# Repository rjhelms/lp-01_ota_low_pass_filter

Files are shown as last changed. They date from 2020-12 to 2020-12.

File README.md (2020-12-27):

# LP-01 OTA Low Pass Filter
[][cc-by-sa]

A Eurorack low-pass filter, in the style of the classic MS-20 circuit, featuring two CV inputs - one adjustable, the other with roughly 1V/oct tracking.

* Width: 8hp
* Depth: 23mm

This project was created with [KiCad](https://kicad.org/).

This work licensed under a
[Creative Commons Attribution-ShareAlike 4.0 International License][cc-by-sa].

[][cc-by-sa]

[cc-by-sa]: http://creativecommons.org/licenses/by-sa/4.0/
[cc-by-sa-image]: https://licensebuttons.net/l/by-sa/4.0/88x31.png
[cc-by-sa-shield]: https://img.shields.io/badge/License-CC%20BY--SA%204.0-lightgrey.svg

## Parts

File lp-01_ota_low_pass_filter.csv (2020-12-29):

Reference | Quantity | Value | Footprint | Datasheet | MFN | Manufacturer | Vendor
C11 C10 C7 C6 C3 C4 | 6 | 100n | Capacitor_THT:C_Disc_D5.0mm_W2.5mm_P2.50mm | ~ | K104K15X7RF5TL2 | Vishay | Digi-Key
C12 | 1 | 470n | Capacitor_THT:C_Disc_D5.0mm_W2.5mm_P2.50mm | ~ | FG18X7R1H474KRT00 | TDK | Digi-Key
C2 C1 | 2 | 10u | Capacitor_THT:CP_Radial_D4.0mm_P1.50mm | ~ | USR1E100MDD1TP | Nichicon | Digi-Key
C5 | 1 | 4n7 | Capacitor_THT:C_Disc_D5.0mm_W2.5mm_P2.50mm | ~ | K472K15X7RH5TL2 | Vishay | Digi-Key
C8 C9 | 2 | 1n | Capacitor_THT:C_Disc_D5.0mm_W2.5mm_P2.50mm | ~ | SR201A102JAR | AVX | Digi-Key
D1 D2 | 2 | LED Green | LED_THT:LED_D5.0mm | ~ | SLR-56MC3F | Rohm | Digi-Key
J3 J1 J2 J4 | 4 | AudioJack2 | Connector_Audio:Jack_3.5mm_QingPu_WQP-PJ398SM_Vertical_CircularHoles | ~ | WQP-PJ398SM | QingPu | Thonk
J5 | 1 | Conn_02x05_Odd_Even | Connector_PinHeader_2.54mm:PinHeader_2x05_P2.54mm_Vertical | ~ | 67997-410HLF | Amphenol ICC / FCI | Digi-Key
Q1 Q2 | 2 | 2N3906 | Package_TO_SOT_THT:TO-92_Inline_Wide | https://www.fairchildsemi.com/datasheets/2N/2N3906.pdf | 2N3906-AP | MCC | Digi-Key
R1 | 1 | 47K | Resistor_THT:R_Axial_DIN0204_L3.6mm_D1.6mm_P5.08mm_Horizontal | ~ | RNMF14FTC47K0 | Stackpole | Digi-Key
R14 R6 R16 R10 R15 R13 | 6 | 10K | Resistor_THT:R_Axial_DIN0204_L3.6mm_D1.6mm_P5.08mm_Horizontal | ~ | RNMF14FAD10K0 | Stackpole | Digi-Key
R17 | 1 | 68K | Resistor_THT:R_Axial_DIN0204_L3.6mm_D1.6mm_P5.08mm_Horizontal | ~ | RNMF14FTC68K0 | Stackpole | Digi-Key
R19 | 1 | 1K0 | Resistor_THT:R_Axial_DIN0204_L3.6mm_D1.6mm_P5.08mm_Horizontal | ~ | RNF18FTD1K00 | Stackpole | Digi-Key
R2 R18 | 2 | 220K | Resistor_THT:R_Axial_DIN0204_L3.6mm_D1.6mm_P5.08mm_Horizontal | ~ | RNMF14FTC220K | Stackpole | Digi-Key
R3 | 1 | 100K | Resistor_THT:R_Axial_DIN0204_L3.6mm_D1.6mm_P5.08mm_Horizontal | ~ | RNF18FTD100K | Stackpole | Digi-Key
R4 | 1 | 4K7 | Resistor_THT:R_Axial_DIN0204_L3.6mm_D1.6mm_P5.08mm_Horizontal | ~ | RNMF14FTC4K70 | Stackpole | Digi-Key
R5 | 1 | 470K | Resistor_THT:R_Axial_DIN0204_L3.6mm_D1.6mm_P5.08mm_Horizontal | ~ | CF18JT470K | Stackpole | Digi-Key
R8 R7 R12 R11 | 4 | 220R | Resistor_THT:R_Axial_DIN0204_L3.6mm_D1.6mm_P5.08mm_Horizontal | ~ | RNMF14FTC220R | Stackpole | Digi-Key
R9 | 1 | 1K8 | Resistor_THT:R_Axial_DIN0204_L3.6mm_D1.6mm_P5.08mm_Horizontal | ~ | RNMF14FTC1K80 | Stackpole | Digi-Key
RV1 RV4 | 2 | B100K | Potentiometer_THT:Potentiometer_Alpha_RD901F-40-00D_Single_Vertical | ~ | RD901F-40-15F-B100K | Alpha | Thonk
RV3 RV2 | 2 | 10K | Potentiometer_Custom:Potentiometer_Bourns_PV36W | ~ | PV36X103C01B00 | Bourns | Digi-Key
RV5 | 1 | A100K | Potentiometer_THT:Potentiometer_Alpha_RD901F-40-00D_Single_Vertical | ~ | RD901F-40-15F-A100K | Alpha | Thonk
U1 | 1 | TL072 | Package_DIP:DIP-8_W7.62mm_Socket | http://www.ti.com/lit/ds/symlink/tl071.pdf | TL072IP | Texas Instruments | Digi-Key
U2 | 1 | LM13700 | Package_DIP:DIP-16_W7.62mm_Socket | http://www.ti.com/lit/ds/symlink/lm13700.pdf | LM13700N/NOPB | Texas Instruments | Digi-Key
U3 | 1 | TL074 | Package_DIP:DIP-14_W7.62mm_Socket | http://www.ti.com/lit/ds/symlink/tl071.pdf | TL074CN | Texas Instruments | Digi-Key
U1 | 1 | DIP-8 socket | Package_DIP:DIP-8_W7.62mm_Socket |  | ED08DT | On Shore Technology | Digi-Key
U2 | 1 | DIP-16 socket | Package_DIP:DIP-16_W7.62mm_Socket |  | ED16DT | On Shore Technology | Digi-Key
U3 | 1 | DIP-14 socket | Package_DIP:DIP-14_W7.62mm_Socket |  | ED14DT | On Shore Technology | Digi-Key

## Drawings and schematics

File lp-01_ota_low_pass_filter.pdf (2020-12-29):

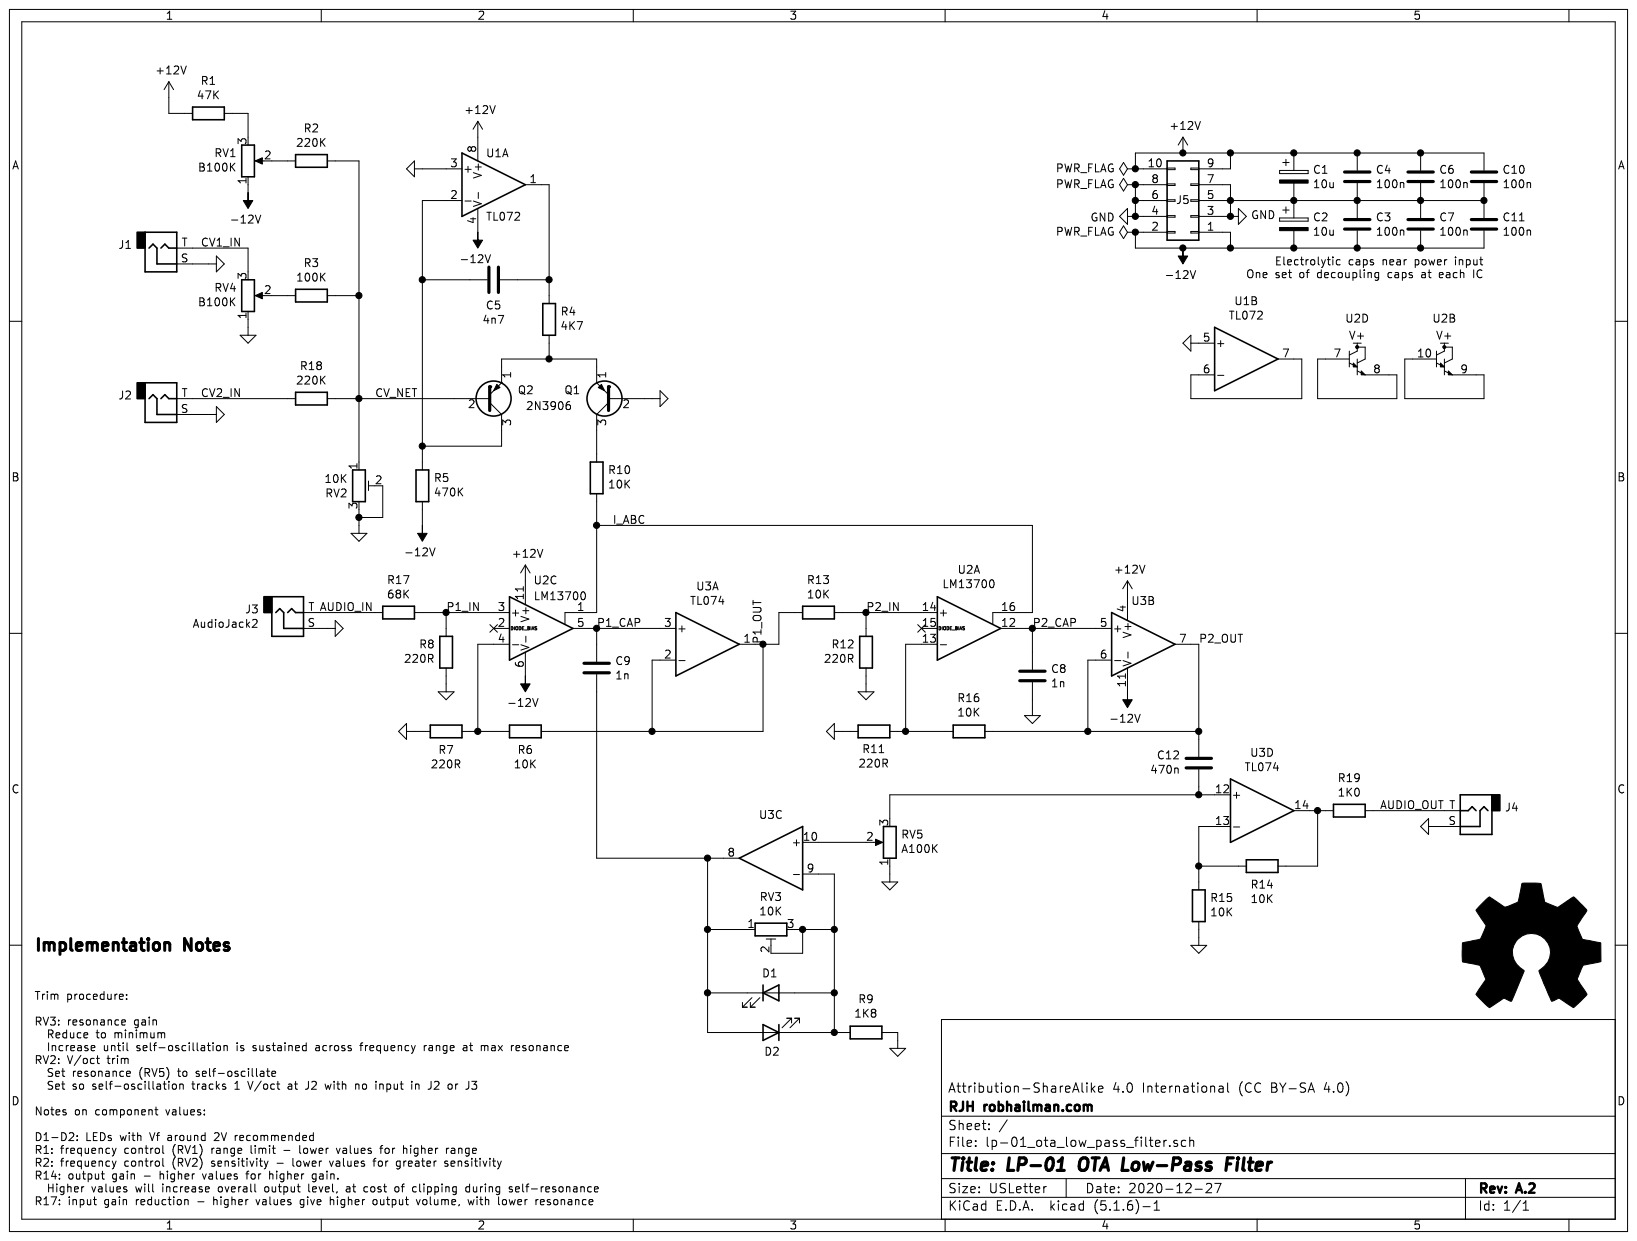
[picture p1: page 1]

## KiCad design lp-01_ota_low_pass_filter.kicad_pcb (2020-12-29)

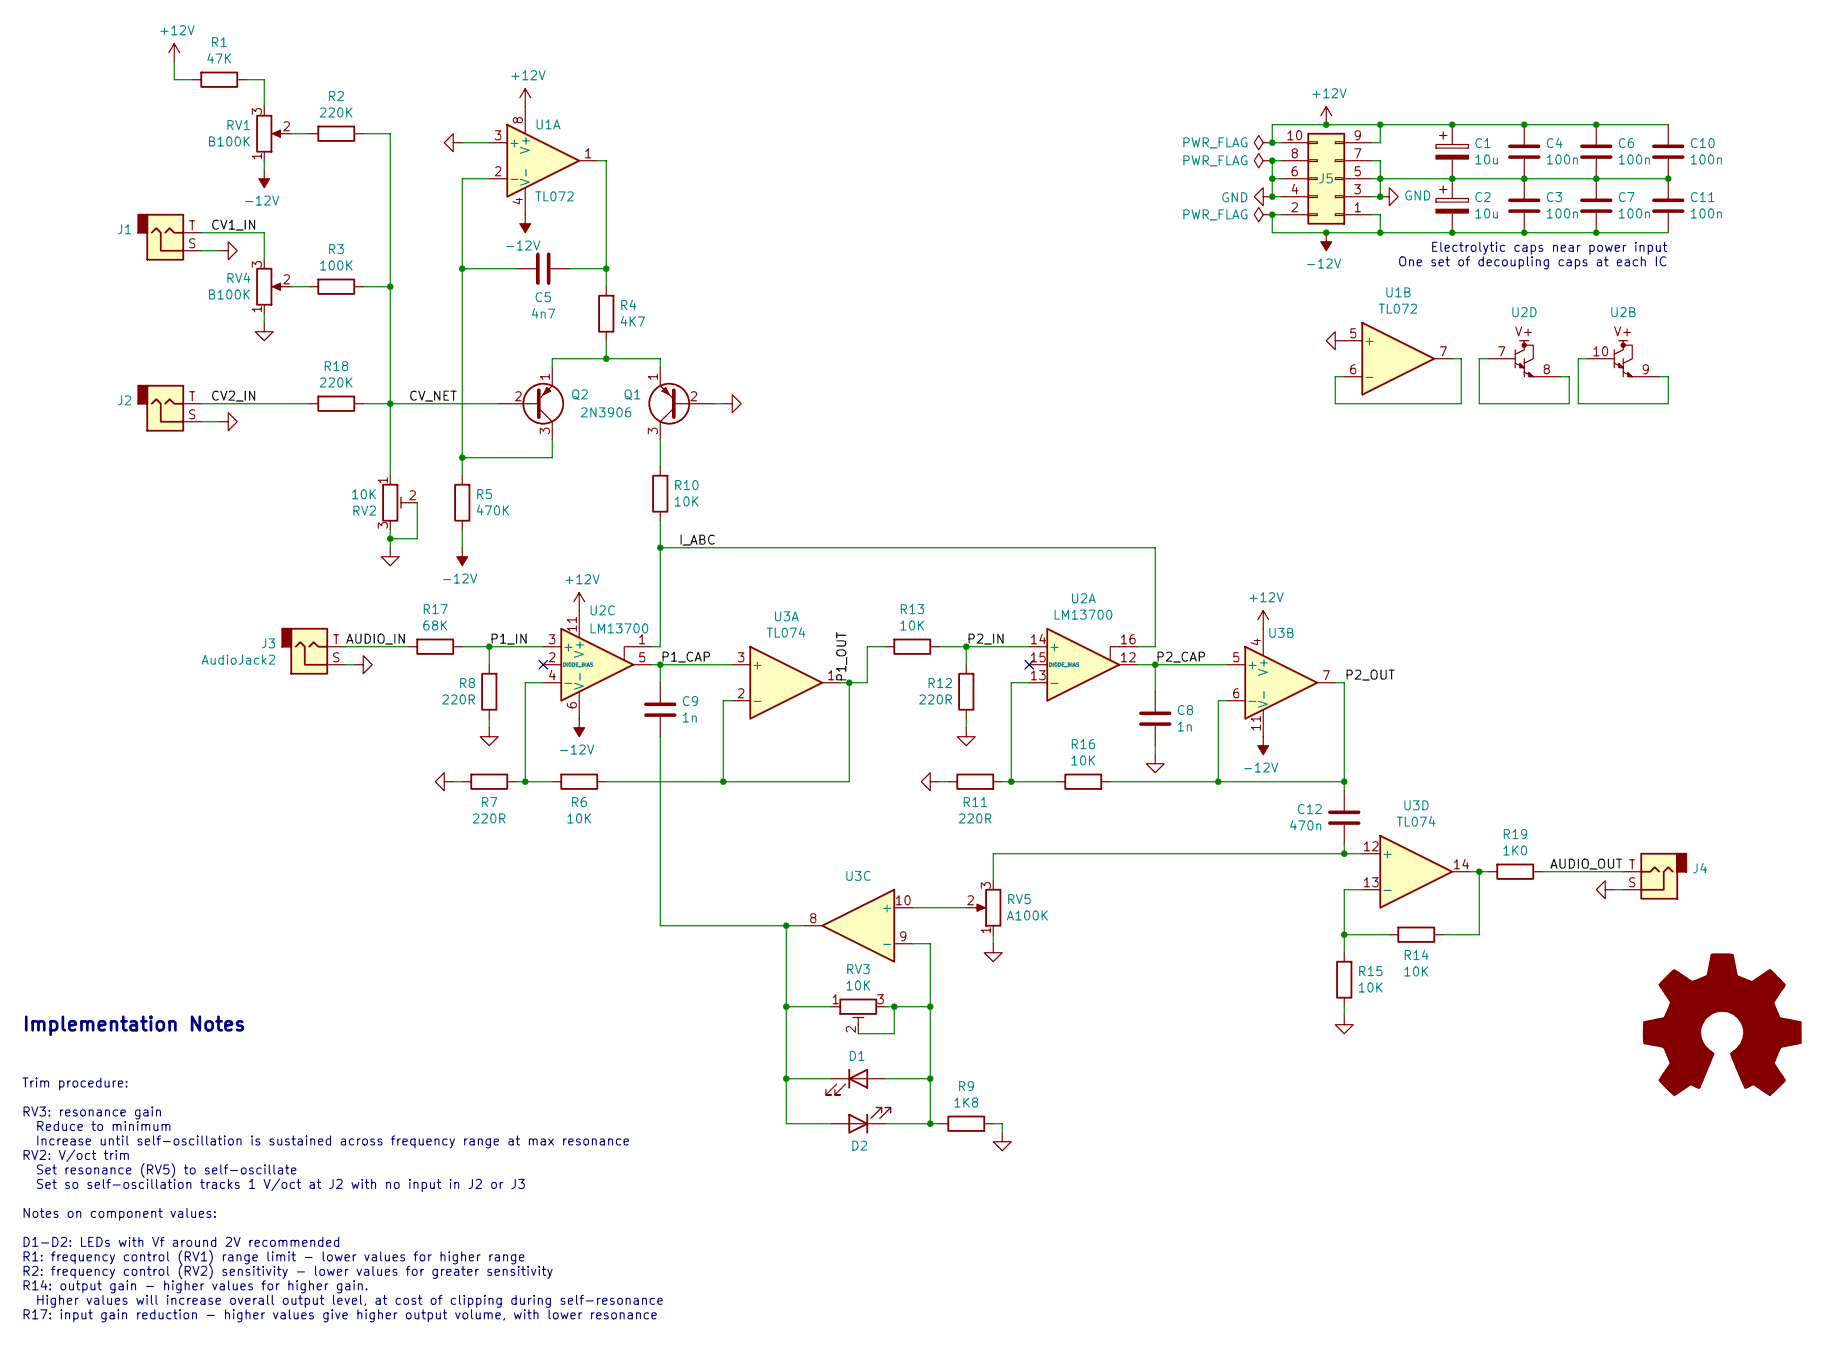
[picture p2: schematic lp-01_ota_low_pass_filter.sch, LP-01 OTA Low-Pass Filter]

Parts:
C1, C2: 10u; CP_Radial_D4.0mm_P1.50mm
C3, C4, C6, C7, C10, C11: 100n; C_Disc_D5.0mm_W2.5mm_P2.50mm
C5: 4n7; C_Disc_D5.0mm_W2.5mm_P2.50mm
C8, C9: 1n; C_Disc_D5.0mm_W2.5mm_P2.50mm
C12: 470n; C_Disc_D5.0mm_W2.5mm_P2.50mm
D1, D2: LED Green; LED_D5.0mm
J1, J2, J3, J4: AudioJack2; Jack_3.5mm_QingPu_WQP-PJ398SM_Vertical_CircularHoles
J5: Conn_02x05_Odd_Even; PinHeader_2x05_P2.54mm_Vertical
LOGO1: Logo_Open_Hardware_Large; OSHW-Logo_5.7x6mm_SilkScreen
Q1, Q2: 2N3906; TO-92_Inline_Wide
R1: 47K; R_Axial_DIN0204_L3.6mm_D1.6mm_P5.08mm_Horizontal
R2, R18: 220K; R_Axial_DIN0204_L3.6mm_D1.6mm_P5.08mm_Horizontal
R3: 100K; R_Axial_DIN0204_L3.6mm_D1.6mm_P5.08mm_Horizontal
R4: 4K7; R_Axial_DIN0204_L3.6mm_D1.6mm_P5.08mm_Horizontal
R5: 470K; R_Axial_DIN0204_L3.6mm_D1.6mm_P5.08mm_Horizontal
R6, R10, R13, R14, R15, R16: 10K; R_Axial_DIN0204_L3.6mm_D1.6mm_P5.08mm_Horizontal
R7, R8, R11, R12: 220R; R_Axial_DIN0204_L3.6mm_D1.6mm_P5.08mm_Horizontal
R9: 1K8; R_Axial_DIN0204_L3.6mm_D1.6mm_P5.08mm_Horizontal
R17: 68K; R_Axial_DIN0204_L3.6mm_D1.6mm_P5.08mm_Horizontal
R19: 1K0; R_Axial_DIN0204_L3.6mm_D1.6mm_P5.08mm_Horizontal
RV1, RV4: B100K; Potentiometer_Alpha_RD901F-40-00D_Single_Vertical
RV2, RV3: 10K; Potentiometer_Bourns_PV36W
RV5: A100K; Potentiometer_Alpha_RD901F-40-00D_Single_Vertical
U1: TL072; DIP-8_W7.62mm_Socket
U2: LM13700; DIP-16_W7.62mm_Socket
U3: TL074; DIP-14_W7.62mm_Socket

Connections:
+12V: C1.1, C4.1, C6.1, C10.1, J5.9, J5.10, R1.2, U1.8 (V+), U2.11 (V+), U3.4 (V+)
-12V: C2.2, C3.2, C7.2, C11.2, J5.1, J5.2, R5.1, RV1.1, U1.4 (V-), U2.6 (V-), U3.11 (V-)
/AUDIO_IN: J3.T, R17.2
/AUDIO_OUT: J4.T, R19.1
/CV1_IN: J1.T, RV4.3
/CV2_IN: J2.T, R18.2
/CV_NET: Q2.2 (B), R2.1, R3.1, R18.1, RV2.1
/I_ABC: R10.1, U2.1, U2.16
/P1_CAP: C9.1, U2.5, U3.3 (+)
/P1_IN: R8.2, R17.1, U2.3 (+)
/P1_OUT: R6.1, R13.2, U3.1, U3.2 (-)
/P2_CAP: C8.1, U2.12, U3.5 (+)
/P2_IN: R12.2, R13.1, U2.14 (+)
/P2_OUT: C12.2, R16.2, U3.6 (-), U3.7
GND: C1.2, C2.1, C3.1, C4.2, C6.2, C7.1, C8.2, C10.2, C11.1, J1.S, J2.S, J3.S, J4.S, J5.3, J5.4, J5.5, J5.6, J5.7, J5.8, Q1.2 (B), R7.2, R8.1, R9.2, R11.1, R12.1, R15.1, RV2.2, RV2.3, RV4.1, RV5.1, U1.3 (+), U1.5 (+)
unnamed: C5.1, R4.2, U1.1
unnamed: C5.2, Q2.3 (C), R5.2, U1.2 (-)
unnamed: C9.2, D1.1 (K), D2.2 (A), RV3.1, U3.8
unnamed: C12.1, RV5.3, U3.12 (+)
unnamed: D1.2 (A), D2.1 (K), R9.1, RV3.2, RV3.3, U3.9 (-)
unnamed: Q1.1 (E), Q2.1 (E), R4.1
unnamed: Q1.3 (C), R10.2
unnamed: R1.1, RV1.3
unnamed: R2.2, RV1.2
unnamed: R3.2, RV4.2
unnamed: R6.2, R7.1, U2.4 (-)
unnamed: R11.2, R16.1, U2.13 (-)
unnamed: R14.1, R19.2, U3.14
unnamed: R14.2, R15.2, U3.13 (-)
unnamed: RV5.2, U3.10 (+)
unnamed: U1.6 (-), U1.7
unnamed: U2.7, U2.8
unnamed: U2.9, U2.10

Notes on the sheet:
Electrolytic caps near power input One set of decoupling caps at each IC
Trim procedure: RV3: resonance gain Reduce to minimum Increase until self-oscillation is sustained across frequency range at max resonance RV2: V/oct trim Set resonance (RV5) to self-oscillate Set so self-oscillation tracks 1 V/oct at J2 with no input in J2 or J3 Notes on component values: D1-D2: L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
Implementation Notes

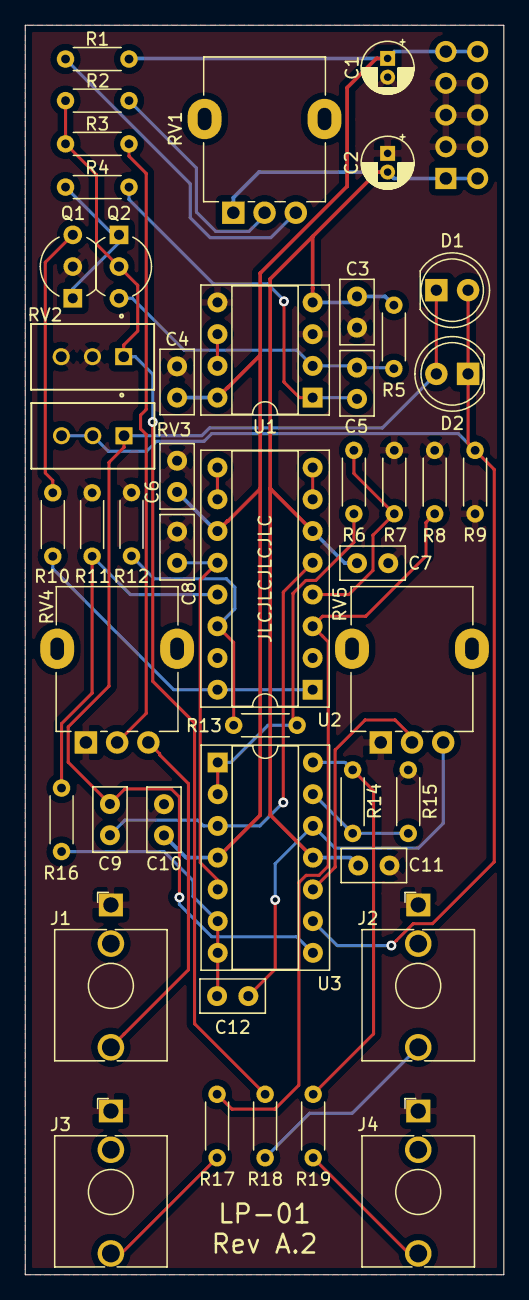
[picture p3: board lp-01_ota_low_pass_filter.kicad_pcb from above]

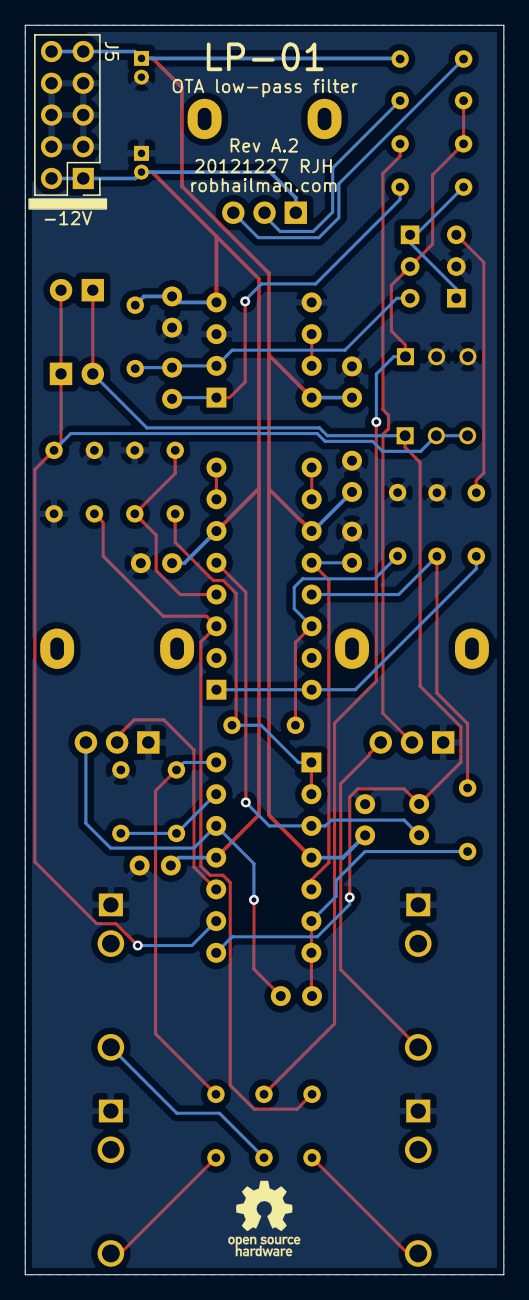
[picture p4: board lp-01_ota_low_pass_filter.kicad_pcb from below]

Board: 2 copper layers, 38.3 x 100.0 mm, 49 parts (2 on the bottom side), 33 nets.

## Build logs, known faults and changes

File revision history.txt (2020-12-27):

Rev A.2
2020-12-26

- Increase value of R1 and RV1 for reduced current draw
- Replace RV5 with B (linear) pot
- Assign CC BY-SA 4.0 license
- Add OSHW logo to schematic and PCBs
- Add robhailman.com URL to schematic and PCBs

Rev A.1
2020-01-17

- Adjust values so CV2 serves as V/oct input
- Replace RV4 with higher impedance non-detented pot

Rev A
2019-09-10

original revision

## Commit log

2019-09-15 Initial commit
    Work to date - before fabbing RevA
    [lp-01-panel.kicad_pcb, lp-01_ota_low_pass_filter.csv, lp-01_ota_low_pass_filter.kicad_pcb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]
2019-09-15 Correct RV2 set instructions
    [lp-01_ota_low_pass_filter.sch]
2019-09-18 Move back side text on panel
    [lp-01-panel.kicad_pcb]
2019-09-18 Finalize settings for RevA export
    [lp-01-panel.kicad_pcb, lp-01_ota_low_pass_filter.kicad_pcb]
2019-10-04 Add IC sockets to BOM
    [lp-01_ota_low_pass_filter.csv]
2020-01-18 Rev A1 - revised component values
    Increase CV1 input impedance, and adjust values for V/oct at CV2
    [lp-01_ota_low_pass_filter.sch]
2020-12-27 Revision A.2
    - A few small component tweaks
    - Add OSHW logos
    - Prepare for public release?
    [lp-01-panel.kicad_pcb, lp-01_ota_low_pass_filter.csv, lp-01_ota_low_pass_filter.kicad_pcb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]
2020-12-29 Revert RV5 to log pot
    This works much better!
    [lp-01_ota_low_pass_filter.kicad_pcb, lp-01_ota_low_pass_filter.sch]
2020-12-29 Update PDF schematic
2020-12-29 Update CSV BOM
    [lp-01_ota_low_pass_filter.csv]

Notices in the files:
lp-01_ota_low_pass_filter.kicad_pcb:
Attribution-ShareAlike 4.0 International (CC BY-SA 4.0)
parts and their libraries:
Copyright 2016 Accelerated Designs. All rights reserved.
